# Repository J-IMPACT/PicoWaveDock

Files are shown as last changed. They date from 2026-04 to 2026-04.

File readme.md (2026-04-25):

# PicoWaveDock クイックスタートガイド

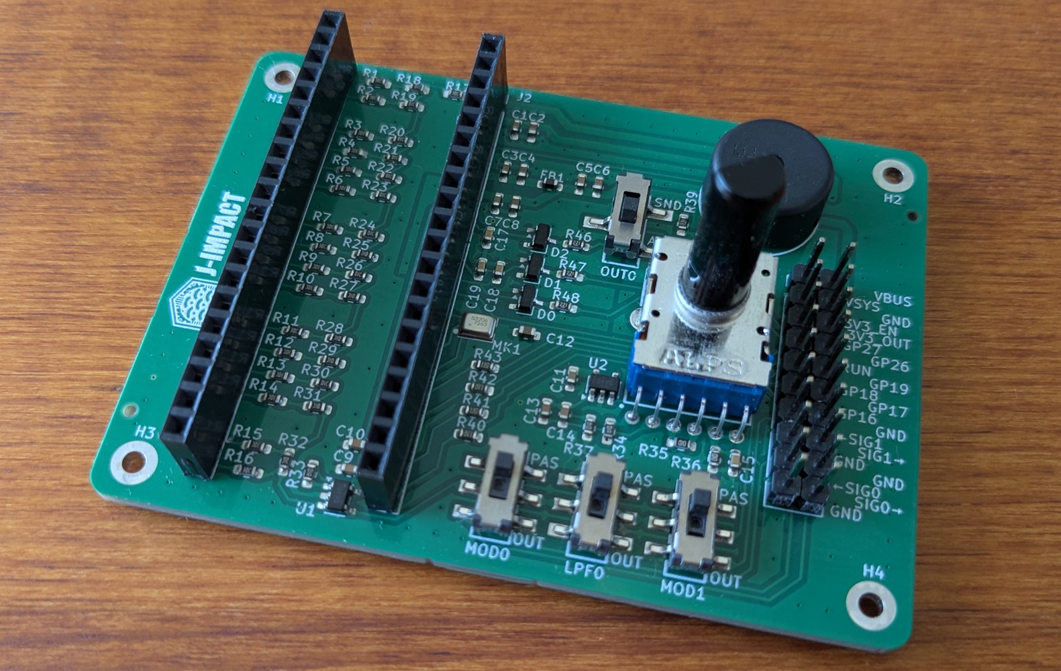
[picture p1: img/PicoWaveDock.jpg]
PicoWaveDock


## 基本的な使い方

1. Raspberry Pi Pico 2（別売り）をソケットにセットする
2. Raspberry Pi Pico 2の **BOOTSELボタン（白いボタン）を押しながら**、USBケーブルでPCに接続する
3. Raspberry Pi Pico 2にコードを書き込む

## 事前準備

- Raspberry Pi Pico 2（別売り）を用意する
- 以下のパーツをはんだ付けする（穴にはまる刺し方であれば、向きは任意）
    - 1x20ピンソケット（2個）
    - 2×10ピンヘッダ
    - 可変抵抗（サイドの固定ピンを少し曲げて調整）
    - スピーカー
- スペーサーを挿入し、ナットで固定する（4か所）

## 操作説明

### スイッチ類

信号は`MOD0`→`LPF0`→`MOD1`→`OUT0`の順に通過。

#### `MOD0`スイッチ

- `PAS`: 何もしない
- `OUT`: `SIG0→`ピンから信号を出力し、`←SIG0`ピンから信号入力を受ける

#### `LPF0`スイッチ

- `PAS`: 何もしない
- `OUT`: 信号をローパスフィルタに通す

#### `MOD1`スイッチ

- `PAS`: 何もしない
- `OUT`: `SIG1→`ピンから信号を出力し、`←SIG1`ピンから信号入力を受ける

#### `OUT0`スイッチ

- `SND`: 信号をスピーカーに出力
- `ADC`: 信号をRaspberry Pi Pico 2の`GPIO28`ピンに入力

### 可変抵抗

ローパスフィルタのカットオフ周波数を変更する。

### 入出力端子

`MOD0`スイッチ・`MOD1`スイッチの入出力端子の他に、Raspberry Pi Pico2の

- VBUS
- VSYS
- GND
- 3V3_EN
- 3V3_OUT
- GPIO27
- GPIO26
- GPIO19
- GPIO18
- GPIO17
- GPIO16

が利用可能。

## ディレクトリの説明

- `open-source-silicon-magazine-vol2`: ISHI会の[「Open Source Silicon Magazine Vol.2 ーマイコンチップを自作しようー」](https://techbookfest.org/product/16QdT05XCLVsRDi1fqX2wy?productVariantID=cNR7b38fA9Ep7S1aKgM5Dy)の記事中で使用した回路図とコード
- `pio-dualcore-book`: [「Rustで学ぶPIOとデュアルコア ーRaspberry Pi Pico 2によるタイミング制御と高速・並列処理ー」](https://techbookfest.org/product/d91HkRw2rxdik7BYVb2BDc?productVariantID=ENVuWDaMN0qXmDj6twDLh)の最終章で使用したサンプルコード
- `wave_example`: 波形生成・計測の各種実装例（Raspberry Pi Pico 2用のRustコード）
- `wave_viewer`: 波形確認用のオシロスコープやスペクトログラムの実装（PC用のRustコード）

## 使用例

事前にRustによる組込み開発環境構築（後述）が必要

### 1kHzの正弦波を出力して、オシロスコープで見る

- スイッチはすべて`PAS`と`ADC`にする

Raspberry Pi Pico2に`wave_example/src/gen_and_scope.rs`を書き込む。
その後、USBケーブルで接続した状態を維持する。

```bash
.../PicoWaveDock> cd wave_example
.../PicoWaveDock/wave_example> cargo run --release --bin gen_and_scope
```

デバイスマネージャ等で、PicoWaveDockが認識されているポート`COMx`を確認し、`wave_viewer/scope.rs`を起動する。

```bash
.../PicoWaveDock> cd wave_viewer
.../PicoWaveDock/wave_example> cargo run --release --bin scope -- --port COMx
```

表示されたウインドウの「▶ Start」ボタンを押し、波形を確認する。

初期状態で、ウインドウの横幅は10 msであるため、10個の波が表示される。

- 波形が出ない場合は、`wave_viewer/scope.rs`を再起動する

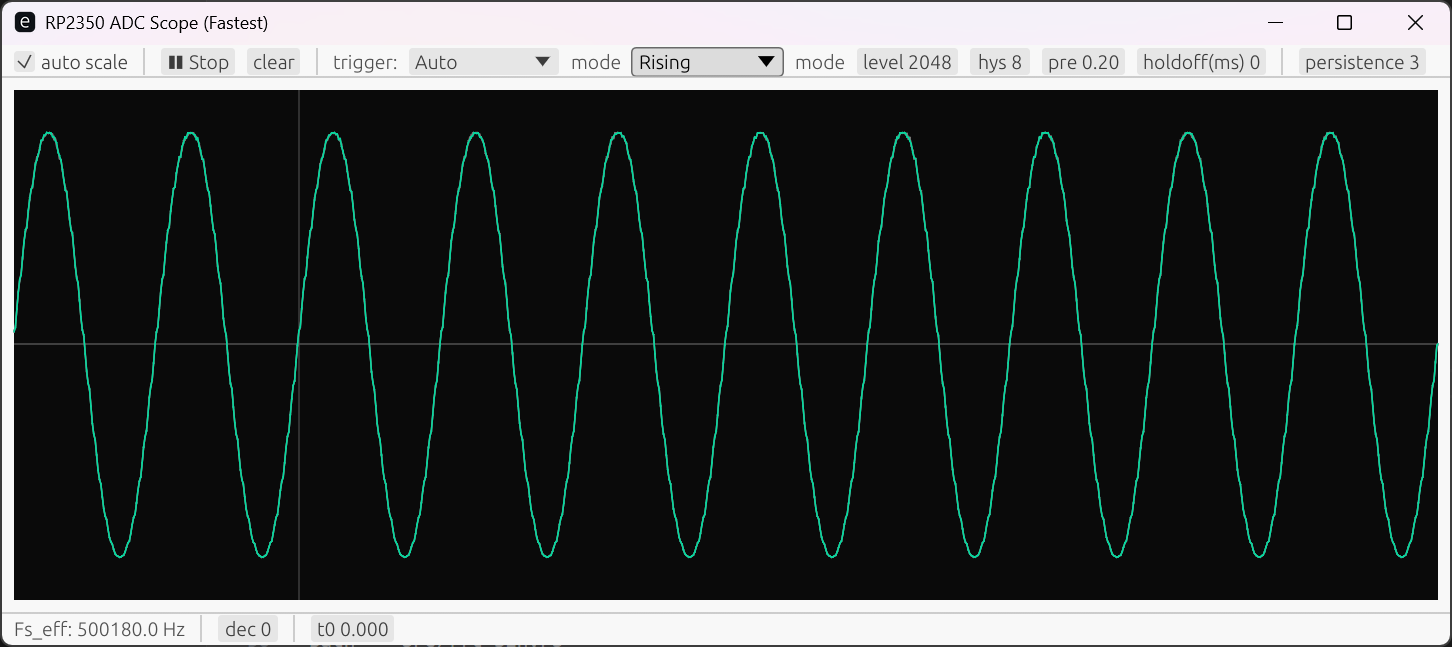
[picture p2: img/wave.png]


### 100Hz～200kHzの正弦波を出力する

- `MOD1`スイッチを`OUT`にして信号を取り出す
- 出力周波数が高い場合（波形が階段状になっている場合）は`LPF0`スイッチを`OUT`にして、ローパスフィルタで平滑化する
- `MOD0`スイッチは`PAS`、`OUT0`スイッチは任意（信号が到達しない）

Raspberry Pi Pico2に`wave_example/src/serial_control_sin.rs`を書き込む。
その後、USBケーブルで接続した状態を維持する。

```bash
.../PicoWaveDock> cd wave_example
.../PicoWaveDock/wave_example> cargo run --release --bin serial_control_sin
```

プログラムの書き込みが完了後もシリアル通信が持続している場合、書き込みに使ったシェルで`Ctrl+C`を実行して通信を終了する。

デバイスマネージャ等で、PicoWaveDockが認識されているポート`COMx`を確認し、[Tera Term](https://teratermproject.github.io/)などのシリアル通信コンソールで通信を開始する。

- コンソール画面が出ない場合は`Enter`キーを押す

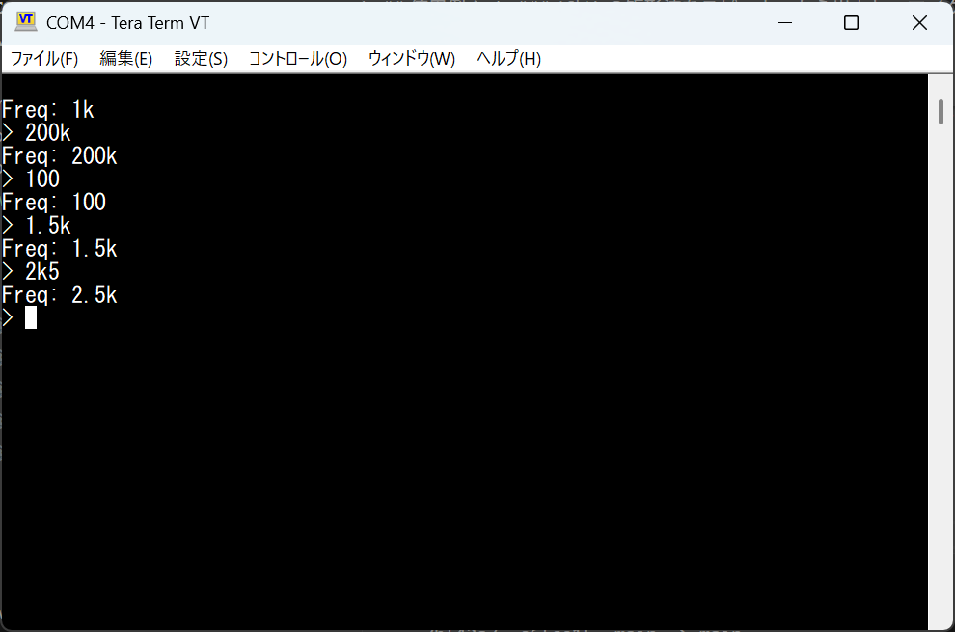
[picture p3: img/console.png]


### 16kHzの矩形波をスピーカーから出力し、マイクでスペクトログラムを見る

- スイッチはすべて`PAS`と`SND`にする

Raspberry Pi Pico2に`wave_example/src/ultrasound_and_specrtrum.rs`を書き込む。
その後、USBケーブルで接続した状態を維持する。

```bash
.../PicoWaveDock> cd wave_example
.../PicoWaveDock/wave_example> cargo run --release --bin ultrasound_and_specrtrum
```

デバイスマネージャ等で、PicoWaveDockが認識されているポート`COMx`を確認し、`wave_viewer/fft_bin.rs`を起動する。

```bash
.../PicoWaveDock> cd wave_viewer
.../PicoWaveDock/wave_example> cargo run --release --bin fft_bin -- --port COMx
```

表示されたウインドウの「▶ Start」ボタンを押し、スペクトログラムを確認する。

16kHzと、その高調波にピークが立つ。

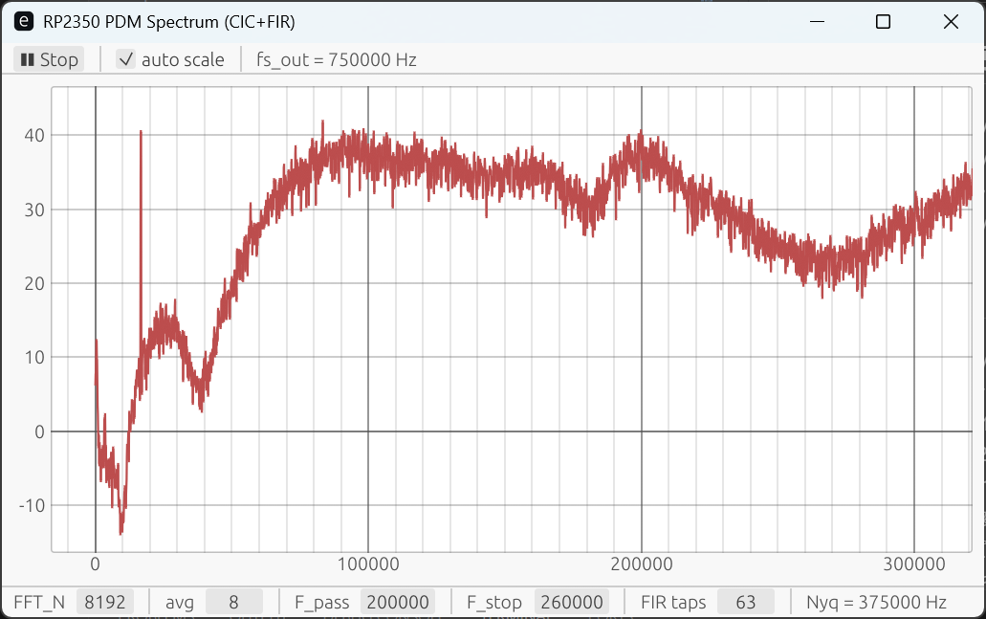
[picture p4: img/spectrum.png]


### 矩形波で演奏

- スイッチはすべて`PAS`と`SND`にする

Raspberry Pi Pico2に`wave_example/src/play_music.rs`を書き込む。

```bash
.../PicoWaveDock> cd wave_example
.../PicoWaveDock/wave_example> cargo run --release --bin play_music
```

「君が代」がスピーカーから出力される。

## （補足）組込みRust環境構築

### 本体のインストール

Rustをインストールする手順は公式サイトを参考にしてください。

- [Rustプログラミング言語（公式）](https://rust-lang.org/ja)
- [Rustのダウンロード（公式）](https://rust-lang.org/ja/learn/get-started/)

インストール作業完了後に以下のコマンドをシェルで実行し、Rustのバージョンが表示されたら、インストールが無事完了したことを確認できます。

```bash
> rustc --version
```

また、既知のバグを避けるため、Rustを最新の状態にしてください。

```bash
> rustup self update
> rustup update stable
```

### 開発ターゲットのインストール

以下のコマンドにより、RP2350向けのビルドターゲットを追加します。

```bash
> rustup target add thumbv8m.main-none-eabihf
```

RP2350への書き込みには**elf2uf2-rs**を使用します。
以下のコマンドにより、インストールしてください。

```bash
> cargo install --git https://github.com/JoNil/elf2uf2-rs --branch master --rev e7361a7 --locked --force
```

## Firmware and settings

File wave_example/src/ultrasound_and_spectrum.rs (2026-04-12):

#![no_std]
#![no_main]

use panic_halt as _;
use rp235x_hal::gpio::FunctionPio1;

use core::cell::{RefCell, UnsafeCell};
use core::sync::atomic::{AtomicBool, Ordering};

use cortex_m::peripheral::NVIC;
use critical_section::Mutex;
use embedded_hal::delay::DelayNs;
use embedded_hal::digital::OutputPin;
use heapless::spsc::Queue;

use rp235x_hal as hal;
use hal::pac;
use pac::interrupt;

use hal::clocks::ClockSource;
use rp235x_hal::dma::{DMAExt, double_buffer, SingleChannel};
use hal::gpio::{bank0, FunctionPio0, Pin, PullDown};
use hal::multicore::{Multicore, Stack};
use hal::pio::{InstalledProgram, PIOExt};
use hal::Sio;
use hal::watchdog::Watchdog;

use usb_device::{class_prelude::*, prelude::*};
use usbd_serial::SerialPort;

const XTAL_FREQ_HZ: u32 = 12_000_000;
const DIV_INT_ULTRASONIC: u16 = 10;
const DIV_INT_LOW_POWER: u16 = 75;

const OUTPUT_HZ: u32 = 100_000;
const PROGRAM_STEP_HZ: u32 = OUTPUT_HZ * 2;
const SQUARE_HZ: u32 = 16_000;
const OUTPUT_PER_SQUARE: u32 = OUTPUT_HZ / SQUARE_HZ;
const SQUARE_HALF: u32 = OUTPUT_PER_SQUARE / 2;
const COUNT_MAX: u32 = u32::MAX / OUTPUT_PER_SQUARE * OUTPUT_PER_SQUARE;
const DAC_MAX: u32 = 65535;

const WORDS_PER_BUF: usize = 2048;    // recommend >= 2048 to reduce IRQ rate
const TOTAL_BYTES: usize = WORDS_PER_BUF * 4;
const N_BUFS: usize = 8;                    // >= 6..12 recommended for burst absorption

const TX_CHUNK: usize = 384;

#[unsafe(link_section = ".start_block")]
#[used]
pub static IMAGE_DEF: hal::block::ImageDef = hal::block::ImageDef::secure_exe();

static CORE1_STACK: Stack<4096> = Stack::new();

static DMA_DONE: AtomicBool = AtomicBool::new(false);

struct PdmPool(UnsafeCell<[[u32; WORDS_PER_BUF]; N_BUFS]>);
unsafe impl Sync for PdmPool {} // we will enforce safety via our own index discipline

static PDM_POOL: PdmPool = PdmPool(UnsafeCell::new([[0; WORDS_PER_BUF]; N_BUFS]));

// Indices queues
static FREE_Q: Mutex<RefCell<Queue<usize, N_BUFS>>> = Mutex::new(RefCell::new(Queue::new()));
static READY_Q: Mutex<RefCell<Queue<usize, N_BUFS>>> = Mutex::new(RefCell::new(Queue::new()));

// SAFETY: caller must ensure no aliasing of the same idx (our DMA/queue discipline does that)
#[inline(always)]
unsafe fn pool_buf_mut(idx: usize) -> &'static mut [u32; WORDS_PER_BUF] {
    unsafe { &mut (*PDM_POOL.0.get())[idx] }
}
// SAFETY: caller must ensure this buffer is not being mutated concurrently (READY_Q buffers are not in DMA)
#[inline(always)]
unsafe fn pool_buf_ref(idx: usize) -> &'static [u32; WORDS_PER_BUF] {
    unsafe { &(*PDM_POOL.0.get())[idx] }
}

#[allow(non_snake_case)]
#[cortex_m_rt::interrupt]
fn DMA_IRQ_0() {
    DMA_DONE.store(true, core::sync::atomic::Ordering::Release);

    let dma = unsafe { &*pac::DMA::ptr() };
    unsafe {
        // ch0 + ch1
        dma.ints0().write(|w| w.bits((1 << 0) | (1 << 1)));
    }
}

#[hal::entry]
fn main() -> ! {
    let mut p = hal::pac::Peripherals::take().unwrap();
    let mut watchdog = Watchdog::new(p.WATCHDOG);

    let clocks = hal::clocks::init_clocks_and_plls(
        XTAL_FREQ_HZ,
        p.XOSC, 
        p.CLOCKS, 
        p.PLL_SYS, 
        p.PLL_USB, 
        &mut p.RESETS, 
        &mut watchdog
    ).ok().unwrap();
    let sys_hz = clocks.system_clock.get_freq().to_Hz();

    let mut timer = hal::Timer::new_timer0(p.TIMER0, &mut p.RESETS, &clocks);

    let mut sio = Sio::new(p.SIO);
    let pins = hal::gpio::Pins::new(
        p.IO_BANK0,
        p.PADS_BANK0,
        sio.gpio_bank0,
        &mut p.RESETS,
    );

    let pio_pins = (
        pins.gpio0.into_function::<FunctionPio0>(),
        pins.gpio1.into_function::<FunctionPio0>(),
        pins.gpio2.into_function::<FunctionPio0>(),
        pins.gpio3.into_function::<FunctionPio0>(),
        pins.gpio4.into_function::<FunctionPio0>(),
        pins.gpio5.into_function::<FunctionPio0>(),
        pins.gpio6.into_function::<FunctionPio0>(),
        pins.gpio7.into_function::<FunctionPio0>(),
        pins.gpio8.into_function::<FunctionPio0>(),
        pins.gpio9.into_function::<FunctionPio0>(),
        pins.gpio10.into_function::<FunctionPio0>(),
        pins.gpio11.into_function::<FunctionPio0>(),
        pins.gpio12.into_function::<FunctionPio0>(),
        pins.gpio13.into_function::<FunctionPio0>(),
        pins.gpio14.into_function::<FunctionPio0>(),
        pins.gpio15.into_function::<FunctionPio0>(),
    );

    let mut a = pio::Assembler::<32>::new();
    let mut wrap_target = a.label();
    let mut wrap_source = a.label();

    // 2 step
    a.bind(&mut wrap_target);
    a.pull(false, true);
    a.out(pio::OutDestination::PINS, 16);
    a.bind(&mut wrap_source);

    let program = a.assemble_with_wrap(wrap_source, wrap_target);

    let (mut pio0, sm0, _, _, _) = p.PIO0.split(&mut p.RESETS);
    let installed = pio0.install(&program).unwrap();

    let mut mc = Multicore::new(&mut p.PSM, &mut p.PPB, &mut sio.fifo);
    let cores = mc.cores();
    let core1 = &mut cores[1];

    core1
        .spawn(CORE1_STACK.take().unwrap(), move || {
            core1_pio_task(sm0, installed, pio_pins, sys_hz)
        })
        .unwrap();

    let dat_pin = pins.gpio20.into_function::<FunctionPio1>();
    let clk_pin = pins.gpio21.into_function::<FunctionPio1>();
    let mut vdd_pin = pins.gpio22.into_push_pull_output();
    let _ = vdd_pin.set_low();

    let side_set = pio::SideSet::new(false, 1, false);
    let mut a = pio::Assembler::<32>::new_with_side_set(side_set);
    let mut wrap_target = a.label();
    let mut wrap_source = a.label();

    let delay: u8 = 1;
    // 4 cycle
    a.bind(&mut wrap_target);
    a.in_with_delay_and_side_set(pio::InSource::PINS, 1, delay, 1);
    a.nop_with_delay_and_side_set(delay, 0);
    a.bind(&mut wrap_source);

    let program = a.assemble_with_wrap(wrap_source, wrap_target);

    let mut led_pin = pins.gpio25.into_push_pull_output();
    let _ = led_pin.set_high().ok();

    let (mut pio1, sm0_pio1, _, _, _) = p.PIO1.split(&mut p.RESETS);
    let installed = pio1.install(&program).unwrap();

    let (mut sm_pio1, rx_pio1, _) = hal::pio::PIOBuilder::from_installed_program(installed)
        .side_set_pin_base(clk_pin.id().num)
        .in_pin_base(dat_pin.id().num)
        .clock_divisor_fixed_point(DIV_INT_LOW_POWER, 0)
        .autopush(true)
        .push_threshold(32)
        .in_shift_direction(hal::pio::ShiftDirection::Right)
        .build(sm0_pio1);
    sm_pio1.set_pindirs([(clk_pin.id().num as u8, hal::pio::PinDir::Output)]);

    let _ = vdd_pin.set_high();
    timer.delay_ms(60);

    let mut sm_pio1 = sm_pio1.start();
    timer.delay_ms(20);

    sm_pio1.set_clock_divisor(DIV_INT_ULTRASONIC as f32);
    timer.delay_ms(12);
    
    let mut dch = p.DMA.dyn_split(&mut p.RESETS);
    let mut ch0 = dch.ch0.take().unwrap();
    let mut ch1 = dch.ch1.take().unwrap();
    ch0.enable_irq0();
    ch1.enable_irq0();
    unsafe { NVIC::unmask(pac::Interrupt::DMA_IRQ_0) };

    // ====== Init free/ready queues ======
    critical_section::with(|cs| {
        let mut fq = FREE_Q.borrow_ref_mut(cs);
        for i in 0..N_BUFS {
            let _ = fq.enqueue(i);
        }
    });

    // Take 2 buffers for ping-pong DMA
    let (idx0, idx1) = critical_section::with(|cs| {
        let mut fq = FREE_Q.borrow_ref_mut(cs);
        (fq.dequeue().unwrap(), fq.dequeue().unwrap())
    });

    let buf0: &'static mut [u32; WORDS_PER_BUF] = unsafe { pool_buf_mut(idx0) };
    let buf1: &'static mut [u32; WORDS_PER_BUF] = unsafe { pool_buf_mut(idx1) };

    // Track which indices correspond to DMA ping/pong sequencing.
    // - dma_cur_idx: the one that just finished on wait()
    // - dma_next_idx: the one currently being filled (already queued)
    let mut dma_cur_idx: usize = idx0;
    let mut dma_next_idx: usize = idx1;

    let mut transfer = double_buffer::Config::new(
        (ch0, ch1), 
        rx_pio1,
        buf0
    ).start().write_next(buf1);

    let usb_bus = UsbBusAllocator::new(hal::usb::UsbBus::new(
        p.USB,
        p.USB_DPRAM,
        clocks.usb_clock,
        true,
        &mut p.RESETS
    ));
    let mut serial = SerialPort::new(&usb_bus);

    let mut usb_dev = UsbDeviceBuilder::new(&usb_bus, UsbVidPid(0x2E8A, 0x000A))
        .device_class(usbd_serial::USB_CLASS_CDC)
        .max_packet_size_0(64).expect("bad EP0 packet size")
        .strings(&[
            StringDescriptors::new(LangID::EN_US) // EN_GBにすると死ぬ
                .manufacturer("Example")
                .product("SPJ0641 PDM Ultrasonic")
                .serial_number("0001")
        ]).expect("failed to set USB strings")
        .build();

    // let mut led_pin = pins.gpio25.into_push_pull_output();
    // let _ = led_pin.set_high().ok();

    // Current buffer being transmitted
    let mut cur_tx_idx: Option<usize> = None;
    let mut cur_byte_off: usize = 0;

    // Small packed TX staging (no full-buffer copy)
    let mut tx_chunk = [0u8; TX_CHUNK];
    let mut tx_chunk_len: usize = 0;
    let mut tx_chunk_off: usize = 0;

    let mut configured = false;

    loop {
        let _ = usb_dev.poll(&mut [&mut serial]);

        if !configured && usb_dev.state() == UsbDeviceState::Configured {
            configured = true;
            // ここで「必ず1回出す」
            let _ = serial.write(b"USB configured\r\n");
        }

        if !configured {
            continue;
        }

        // === 1) USB TX: if stagged chunk exists, flush it ===
        if tx_chunk_off < tx_chunk_len {
            match serial.write(&tx_chunk[tx_chunk_off..tx_chunk_len]) {
                Ok(0) | Err(_) => {}
                Ok(n) => {
                    tx_chunk_off += n;
                    if tx_chunk_off >= tx_chunk_len {
                        tx_chunk_off = 0;
                        tx_chunk_len = 0;
                    }
                }
            }
        } else {
            // === 2) No stagged chunk: build next packed chunk from ready buffers ===

            // If no current buffer, grab one from READY_Q
            if cur_tx_idx.is_none() {
                cur_tx_idx = critical_section::with(|cs| {
                    let mut rq = READY_Q.borrow_ref_mut(cs);
                    rq.dequeue()
                });
                cur_byte_off = 0;
            }

            if let Some(idx) = cur_tx_idx {
                let words = unsafe { pool_buf_ref(idx) };

                if cur_byte_off < TOTAL_BYTES {
                    let mut woff = cur_byte_off / 4;
                    let mut boff = cur_byte_off % 4;

                    let mut out_n = 0usize;

                    while out_n < TX_CHUNK && (woff < WORDS_PER_BUF) {
                        let le = words[woff].to_le_bytes();

                        while out_n < TX_CHUNK && boff < 4 {
                            tx_chunk[out_n] = le[boff];
                            out_n += 1;
                            boff += 1;
                        }

                        if boff >= 4 {
                            boff = 0;
                            woff += 1;
                        }
                    }

                    cur_byte_off += out_n;
                    tx_chunk_len = out_n;
                    tx_chunk_off = 0;
                } else {
                    critical_section::with(|cs| {
                        let mut fq = FREE_Q.borrow_ref_mut(cs);
                        let _ = fq.enqueue(idx);
                    });
                    cur_tx_idx = None;
                    cur_byte_off = 0;
                }
            }
        }

        // === 3) DMA completion handling ===
        if DMA_DONE.swap(false, Ordering::AcqRel) {
            let (_filled_buf, next) = transfer.wait();

            // The finished buffer index is known by sequencing, not by pointer probing.
            let filled_idx = dma_cur_idx;

            // After wait(), the "current" for the next cycle is what used to be dma_next_idx.
            dma_cur_idx = dma_next_idx;

            // Try to get a new buffer to schedule after the one currently being filled.
            let schedule_idx_opt = critical_section::with(|cs| {
                let mut fq = FREE_Q.borrow_ref_mut(cs);
                fq.dequeue()
            });

            let sched_buf = if let Some(schedule_idx) = schedule_idx_opt {
                // We have a fresh buffer to schedule, so we can keep filled_idx (if READY_Q has space).
                let pushed = critical_section::with(|cs| {
                    let mut rq = READY_Q.borrow_ref_mut(cs);
                    rq.enqueue(filled_idx).is_ok()
                });

                if !pushed {
                    critical_section::with(|cs| {
                        let mut fq = FREE_Q.borrow_ref_mut(cs);
                        let _ = fq.enqueue(filled_idx);
                    });
                }
                dma_next_idx = schedule_idx;
                unsafe { pool_buf_mut(schedule_idx) }
            } else {
                dma_next_idx = filled_idx;
                unsafe { pool_buf_mut(filled_idx) }
            };

            transfer = next.write_next(sched_buf);
        }
    }
}

fn core1_pio_task(
    sm0: hal::pio::UninitStateMachine<(hal::pac::PIO0, hal::pio::SM0)>,
    installed: InstalledProgram<hal::pac::PIO0>,
    pio_pins: (
        Pin<bank0::Gpio0, FunctionPio0, PullDown>,
        Pin<bank0::Gpio1, FunctionPio0, PullDown>,
        Pin<bank0::Gpio2, FunctionPio0, PullDown>,
        Pin<bank0::Gpio3, FunctionPio0, PullDown>,
        Pin<bank0::Gpio4, FunctionPio0, PullDown>,
        Pin<bank0::Gpio5, FunctionPio0, PullDown>,
        Pin<bank0::Gpio6, FunctionPio0, PullDown>,
        Pin<bank0::Gpio7, FunctionPio0, PullDown>,
        Pin<bank0::Gpio8, FunctionPio0, PullDown>,
        Pin<bank0::Gpio9, FunctionPio0, PullDown>,
        Pin<bank0::Gpio10, FunctionPio0, PullDown>,
        Pin<bank0::Gpio11, FunctionPio0, PullDown>,
        Pin<bank0::Gpio12, FunctionPio0, PullDown>,
        Pin<bank0::Gpio13, FunctionPio0, PullDown>,
        Pin<bank0::Gpio14, FunctionPio0, PullDown>,
        Pin<bank0::Gpio15, FunctionPio0, PullDown>,
    ),
    sys_hz: u32
) -> ! {
    let d0 = pio_pins.0;
    let _d1 = pio_pins.1;
    let _d2 = pio_pins.2;
    let _d3 = pio_pins.3;
    let _d4 = pio_pins.4;
    let _d5 = pio_pins.5;
    let _d6 = pio_pins.6;
    let _d7 = pio_pins.7;
    let _d8 = pio_pins.8;
    let _d9 = pio_pins.9;
    let _d10 = pio_pins.10;
    let _d11 = pio_pins.11;
    let _d12 = pio_pins.12;
    let _d13 = pio_pins.13;
    let _d14 = pio_pins.14;
    let _d15 = pio_pins.15;

    let int = (sys_hz / PROGRAM_STEP_HZ) as u16;
    let rem = sys_hz % PROGRAM_STEP_HZ;
    let frac = ((rem * 256) / PROGRAM_STEP_HZ) as u8;
    let (mut sm, _, mut tx) = hal::pio::PIOBuilder::from_installed_program(installed)
        .out_pins(d0.id().num, 16)
        .clock_divisor_fixed_point(int, frac)
        .build(sm0);
    sm.set_pindirs((0..16 as u8).map(|pin| (pin, hal::pio::PinDir::Output)));
    sm.start();

    let mut count: u32 = 0;
    loop {
        let output = if (count / SQUARE_HALF) % 2 == 0 { DAC_MAX } else { 0 };

        while tx.is_full() {}
        tx.write(output);
        
        count = count.wrapping_add(1);
        if count >= COUNT_MAX { count = 0; }
    }
}

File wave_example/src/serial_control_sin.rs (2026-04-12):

#![no_std]
#![no_main]

use panic_halt as _;
use rp235x_hal::sio::{Lane, LaneCtrl};

use core::cell::UnsafeCell;
use core::sync::atomic::{AtomicU32, Ordering};

use embedded_hal::digital::OutputPin;
use heapless::String;

use rp235x_hal as hal;

use hal::clocks::ClockSource;
use rp235x_hal::dma::{DMAExt, double_buffer};
use hal::gpio::{bank0, FunctionPio0, Pin, PullDown};
use hal::multicore::{Multicore, Stack};
use hal::pio::{InstalledProgram, PIOExt};
use hal::Sio;
use hal::watchdog::Watchdog;

use usb_device::{class_prelude::*, prelude::*};
use usbd_serial::SerialPort;

use wave_example::tables::SINE_LUT;

const XTAL_FREQ_HZ: u32 = 12_000_000;

const OUTPUT_HZ: u32 = 2_000_000;
const PROGRAM_STEP_HZ: u32 = OUTPUT_HZ * 2;

const LUT_BITS: u32 = 12;
const LUT_LEN: usize = 1 << LUT_BITS;

const DDS_HZ_DEFAULT: u32 = 1_000;

const DDS_BUF_SAMPLES: usize = 1024;

static CORE1_STACK: Stack<4096> = Stack::new();

static DDS_FREQ: AtomicU32 = AtomicU32::new(DDS_HZ_DEFAULT);

#[unsafe(link_section = ".start_block")]
#[used]
pub static IMAGE_DEF: hal::block::ImageDef = hal::block::ImageDef::secure_exe();

struct DdsPool(UnsafeCell<[[u32; DDS_BUF_SAMPLES]; 2]>);
unsafe impl Sync for DdsPool {}
static DDS_POOL: DdsPool = DdsPool(UnsafeCell::new([[0u32; DDS_BUF_SAMPLES]; 2]));

#[inline(always)]
unsafe fn dds_buf_mut(i: usize) -> &'static mut [u32; DDS_BUF_SAMPLES] {
    unsafe { &mut (*DDS_POOL.0.get())[i] }
}

#[hal::entry]
fn main() -> ! {

    let mut p = hal::pac::Peripherals::take().unwrap();
    let mut watchdog = Watchdog::new(p.WATCHDOG);

    let clocks = hal::clocks::init_clocks_and_plls(
        XTAL_FREQ_HZ,
        p.XOSC,
        p.CLOCKS,
        p.PLL_SYS,
        p.PLL_USB,
        &mut p.RESETS,
        &mut watchdog
    ).ok().unwrap();

    let sys_hz = clocks.system_clock.get_freq().to_Hz();

    let mut sio = Sio::new(p.SIO);

    let pins = hal::gpio::Pins::new(
        p.IO_BANK0,
        p.PADS_BANK0,
        sio.gpio_bank0,
        &mut p.RESETS
    );

    let pio_pins = (
        pins.gpio0.into_function::<FunctionPio0>(),
        pins.gpio1.into_function::<FunctionPio0>(),
        pins.gpio2.into_function::<FunctionPio0>(),
        pins.gpio3.into_function::<FunctionPio0>(),
        pins.gpio4.into_function::<FunctionPio0>(),
        pins.gpio5.into_function::<FunctionPio0>(),
        pins.gpio6.into_function::<FunctionPio0>(),
        pins.gpio7.into_function::<FunctionPio0>(),
        pins.gpio8.into_function::<FunctionPio0>(),
        pins.gpio9.into_function::<FunctionPio0>(),
        pins.gpio10.into_function::<FunctionPio0>(),
        pins.gpio11.into_function::<FunctionPio0>(),
        pins.gpio12.into_function::<FunctionPio0>(),
        pins.gpio13.into_function::<FunctionPio0>(),
        pins.gpio14.into_function::<FunctionPio0>(),
        pins.gpio15.into_function::<FunctionPio0>(),
    );

    let mut a = pio::Assembler::<32>::new();
    let mut wrap_target = a.label();
    let mut wrap_source = a.label();

    a.bind(&mut wrap_target);
    a.pull(false, true);
    a.out(pio::OutDestination::PINS, 16);
    a.bind(&mut wrap_source);

    let program = a.assemble_with_wrap(wrap_source, wrap_target);

    let (mut pio0, sm0, _, _, _) = p.PIO0.split(&mut p.RESETS);
    let installed = pio0.install(&program).unwrap();

    let mut dch = p.DMA.dyn_split(&mut p.RESETS);

    let pio_ch2 = dch.ch2.take().unwrap();
    let pio_ch3 = dch.ch3.take().unwrap();

    let mut mc = Multicore::new(&mut p.PSM, &mut p.PPB, &mut sio.fifo);
    let cores = mc.cores();
    let core1 = &mut cores[1];

    let interp0 = sio.interp0;

    core1.spawn(CORE1_STACK.take().unwrap(), move || {
        core1_dds_pio_dma_task(
            sm0,
            installed,
            pio_pins,
            sys_hz,
            interp0,
            pio_ch2,
            pio_ch3
        )
    }).unwrap();

    let usb_bus = UsbBusAllocator::new(hal::usb::UsbBus::new(
        p.USB,
        p.USB_DPRAM,
        clocks.usb_clock,
        true,
        &mut p.RESETS
    ));

    let mut serial = SerialPort::new(&usb_bus);

    let mut usb_dev = UsbDeviceBuilder::new(&usb_bus, UsbVidPid(0x2E8A, 0x000A))
        .device_class(usbd_serial::USB_CLASS_CDC)
        .max_packet_size_0(64).unwrap()
        .strings(&[
            StringDescriptors::new(LangID::EN_US)
                .manufacturer("Example")
                .product("DDS Generator")
                .serial_number("0001")
        ]).unwrap()
        .build();

    let mut rx_buf = [0u8; 64];
    let mut cmd = String::<16>::new();

    let mut configured = false;

    let mut led_pin = pins.gpio25.into_push_pull_output();
    let _ = led_pin.set_high();

    loop {
        if !usb_dev.poll(&mut [&mut serial]) {
            continue;
        }

        if usb_dev.state() == UsbDeviceState::Configured && !configured {

            configured = true;

            let f = DDS_FREQ.load(Ordering::Relaxed);

            let mut buf = String::<32>::new();
            let _ = core::fmt::write(&mut buf, format_args!("Freq: {}\r\n> ", f));

            usb_write(&mut serial, &buf);
        }

        if let Ok(count) = serial.read(&mut rx_buf) {

            for &b in &rx_buf[..count] {

                match b {

                    b'\r' | b'\n' => {

                        usb_write(&mut serial, "\r\n");

                        if let Some(mut v) = parse_freq(&cmd) {

                            if v > 200000 { v = 200000; }
                            if v < 100 { v = 100; }

                            DDS_FREQ.store(v, Ordering::Relaxed);

                            let mut buf = String::<32>::new();

                            buf.push_str("Freq: ").ok();
                            format_freq(v, &mut buf);
                            buf.push_str("\r\n> ").ok();

                            usb_write(&mut serial, &buf);

                        } else {

                            usb_write(&mut serial, "Invalid\r\n> ");
                        }

                        cmd.clear();
                    }

                    8 | 127 => {

                        if !cmd.is_empty() {
                            cmd.pop();
                            usb_write(&mut serial, "\x08 \x08");
                        }
                    }

                    _ => {

                        if cmd.push(b as char).is_ok() {
                            let _ = serial.write(&[b]);
                        }
                    }
                }
            }
        }
    }
}

fn usb_write(serial: &mut SerialPort<'_, hal::usb::UsbBus>, s: &str) {
    let mut bytes = s.as_bytes();
    while !bytes.is_empty() {
        match serial.write(bytes) {
            Ok(n) => bytes = &bytes[n..],
            Err(_) => {}
        }
    }
}
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

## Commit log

2026-04-08 add book sample
2026-04-12 add circuit
    [pico_wave_dock_ishikai.kicad_sch]
